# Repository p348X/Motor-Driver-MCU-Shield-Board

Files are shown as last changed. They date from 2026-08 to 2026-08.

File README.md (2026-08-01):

# PICTURES 
 
 
Screenshot From 2026-07-31 14-38-00
Screenshot From 2026-07-31 14-37-28

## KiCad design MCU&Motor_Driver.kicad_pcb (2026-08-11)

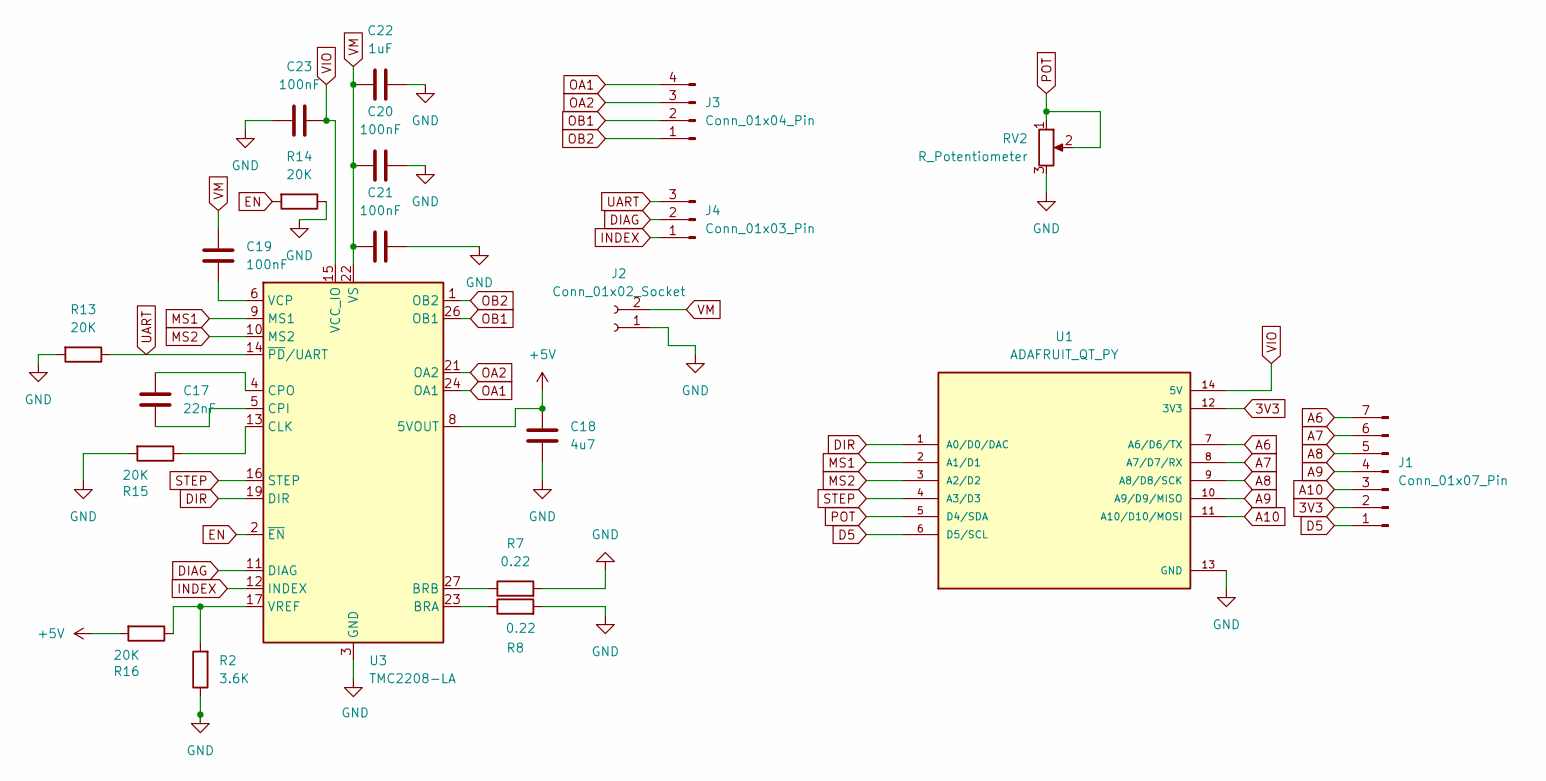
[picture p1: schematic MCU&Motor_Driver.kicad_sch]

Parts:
C17: 22nF; C_0805_2012Metric
C18: 4u7; C_0201_0603Metric_Pad0.64x0.40mm_HandSolder
C19, C20, C21, C23: 100nF; C_0402_1005Metric
C22: 1uF; C_0402_1005Metric
J1: Conn_01x07_Pin; PinHeader_1x07_P2.54mm_Vertical
J2: Conn_01x02_Socket; PinHeader_1x02_P2.54mm_Vertical_SMD_Pin1Left
J3: Conn_01x04_Pin; JST_EH_B4B-EH-A_1x04_P2.50mm_Vertical
J4: Conn_01x03_Pin; PinHeader_1x03_P2.54mm_Vertical
R2: 3.6K; R_0402_1005Metric
R7, R8: 0.22; R_0402_1005Metric
R13, R14, R15, R16: 20K; R_0402_1005Metric
RV2: R_Potentiometer; Potentiometer_Bourns_PTV09A-1_Single_Vertical
U1: ADAFRUIT_QT_PY; MODULE_ADAFRUIT_QT_PY; PARTREV 2022-12-12
U3: TMC2208-LA; QFN-28-1EP_5x5mm_P0.5mm_EP3.1x3.1mm

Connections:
3V3: J1.2, U1.12 (3V3)
+5V: C18.1, R16.2, U3.8 (5VOUT)
A6: J1.7, U1.7 (A6/D6/TX)
A7: J1.6, U1.8 (A7/D7/RX)
A8: J1.5, U1.9 (A8/D8/SCK)
A9: J1.4, U1.10 (A9/D9/MISO)
A10: J1.3, U1.11 (A10/D10/MOSI)
D5: J1.1, U1.6 (D5/SCL)
DIAG: J4.2, U3.11 (DIAG)
DIR: U1.1 (A0/D0/DAC), U3.19 (DIR)
EN: R14.2, U3.2 (~EN)
GND: C18.2, C20.2, C21.2, C22.2, C23.1, J2.1, R2.1, R7.2, R8.2, R13.2, R14.1, R15.2, RV2.3, U1.13 (GND), U3.3 (GND), U3.18 (GND), U3.29 (GND)
INDEX: J4.1, U3.12 (INDEX)
MS1: U1.2 (A1/D1), U3.9 (MS1)
MS2: U1.3 (A2/D2), U3.10 (MS2)
unnamed: R8.1, U3.23 (BRA)
unnamed: R7.1, U3.27 (BRB)
unnamed: R15.1, U3.13 (CLK)
unnamed: C17.1, U3.5 (CPI)
unnamed: C17.2, U3.4 (CPO)
unnamed: C19.1, U3.6 (VCP)
unnamed: R2.2, R16.1, U3.17 (VREF)
OA1: J3.4, U3.24 (OA1)
OA2: J3.3, U3.21 (OA2)
OB1: J3.2, U3.26 (OB1)
OB2: J3.1, U3.1 (OB2)
POT: RV2.1, RV2.2, U1.5 (D4/SDA)
STEP: U1.4 (A3/D3), U3.16 (STEP)
UART: J4.3, R13.1, U3.14 (~PD/UART)
VIO: C23.2, U1.14 (5V), U3.15 (VCC_IO)
VM: C19.2, C20.1, C21.1, C22.1, J2.2, U3.22 (VS), U3.28 (VS)

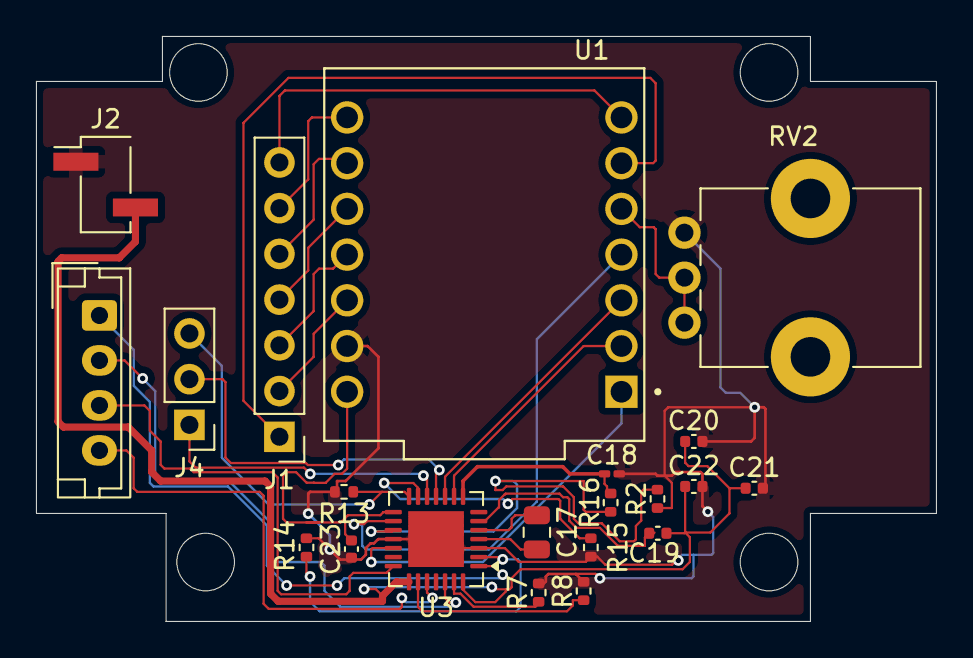
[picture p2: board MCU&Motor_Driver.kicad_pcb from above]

Board: 4 copper layers, 50.0 x 32.5 mm, 21 parts (0 on the bottom side), 31 nets.

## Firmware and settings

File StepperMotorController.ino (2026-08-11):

#define MS1 A1   
#define MS2 A2   
#define DIR  A0   
#define STEP A3   
#define POT SDA   
const int   STEPS_PER_REV   = 200;       
const int   ADC_MAX         = 4095;      
const int   DEADBAND        = 15;        
const int   MIN_STEP_DELAY  = 400;       
const int   MAX_STEP_DELAY  = 4000;      
int previousPotValue = 0;
int currentStepPosition = 0;
int targetStepPosition  = 0;

void setup() {
  pinMode(MS1,  OUTPUT);
  pinMode(MS2,  OUTPUT);
  pinMode(DIR,  OUTPUT);
  pinMode(STEP, OUTPUT);
  digitalWrite(MS1, LOW);
  digitalWrite(MS2, LOW);
  digitalWrite(STEP, LOW);

  previousPotValue = analogRead(POT);
  currentStepPosition = map(previousPotValue, 0, ADC_MAX, 0, STEPS_PER_REV);
  targetStepPosition  = currentStepPosition;
}

void loop() {
  int potValue = analogRead(POT);

  if (abs(potValue - previousPotValue) > DEADBAND) {

    targetStepPosition = map(potValue, 0, ADC_MAX, 0, STEPS_PER_REV);
    int delta = abs(potValue - previousPotValue);
    int stepDelay = map(delta, DEADBAND, ADC_MAX, MAX_STEP_DELAY, MIN_STEP_DELAY);
    stepDelay = constrain(stepDelay, MIN_STEP_DELAY, MAX_STEP_DELAY);git
    if (targetStepPosition > currentStepPosition) {
      digitalWrite(DIR, HIGH);
    } else {
      digitalWrite(DIR, LOW);
    }
    if (currentStepPosition != targetStepPosition) {
      digitalWrite(STEP, HIGH);
      delayMicroseconds(stepDelay);
      digitalWrite(STEP, LOW);
      delayMicroseconds(stepDelay);
      if (targetStepPosition > currentStepPosition) {
        currentStepPosition++;
      } else {
        currentStepPosition--;
      }
    }

    previousPotValue = potValue;
  }
}

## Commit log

2026-08-01 This is commit is of all of the work I have done for this project and the relevant KiCad Files
    [MCU&Motor_Driver.kicad_pcb, MCU&Motor_Driver.kicad_sch]
2026-08-11 Added a voltage divider to the vref pin on the TMC2208 such as to limit the max current to 0.5A based of the NEMA 14 motor I am using this for and also grounded the EN pin on the TMC2208 as to not ha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
    [MCU&Motor_Driver.kicad_pcb, MCU&Motor_Driver.kicad_sch]
2026-08-11 Add files via upload
    Arduino code
